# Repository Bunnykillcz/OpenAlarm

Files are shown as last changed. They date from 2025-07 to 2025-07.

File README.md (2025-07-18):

<p align="center">
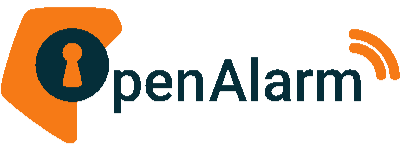
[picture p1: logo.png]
OpenAlarm Logo
  
</p>

<h1 align="center">OpenAlarm – Arduino Nano Opensource Alarm System</h1>

---
<p align="center">
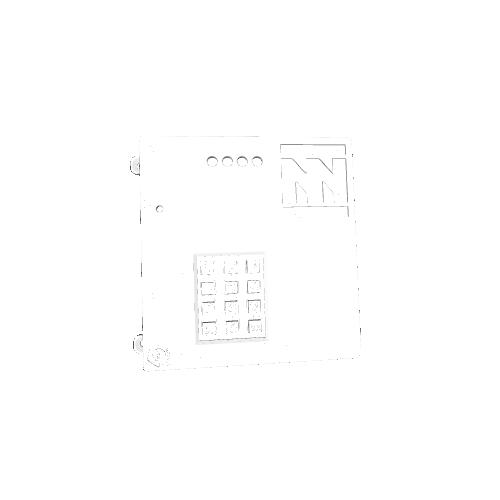
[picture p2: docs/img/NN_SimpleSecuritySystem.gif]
OpenAlarm Preview
  
</p>

## 📦 Overview

**OpenAlarm** is a fully open-source Arduino Nano–based hardware project, designed for hobbyists, students, and makers. The repository contains everything needed to build it, understand how it works, and adapt it to your own needs — **for personal and non-commercial use only**.

Included in this repo:

- ✅ Arduino Nano source code  
- 🔌 Electrical schematics and wiring diagrams  
- 📐 Mechanical dimensions (STL, DXF, etc.)  
- 📄 Full documentation and bill of materials  

---

## 🛠 What's Inside

- `/code` – Arduino sketches and libraries  
- `/schematics` – Circuit diagrams (PDF, Fritzing, etc.)  
- `/dimensions` – Mechanical files (STL, DXF, etc.)  
- `/docs` – Assembly guide, setup instructions, BOM  

---

## 🔧 Requirements

- Arduino Nano board  
- Components as listed in [`/docs/BOM.md`](/docs/BOM.md)
- Basic tools: soldering iron, USB cable, multimeter, etc.

---

## ⚖️ License

**Creative Commons Attribution-NonCommercial 4.0 International (CC BY-NC 4.0)**

> You are free to use, modify, and share this project **for personal or educational use only**. Commercial use is **not allowed**.

[Read the full license →](https://creativecommons.org/licenses/by-nc/4.0/)

For any inquiries, contact me at **info@nejedniko.cz**.

---

## 🤝 Contributions

Pull requests are welcome! If you have improvements, ideas, or bugfixes, feel free to fork and submit a PR.

---

## 📬 Contact

Submit issues in the [Issues](../../issues) tab.  
For anything else, contact me directly at **info@nejedniko.cz**.

---

## 💸 Support

Like the project?  
Want to keep the caffeine flowing so I can keep building stuff that beeps and blinks?

☕ **Invest in my caffeine addiction here:**  
[https://ko-fi.com/bunnykill](https://ko-fi.com/bunnykill)

---

> Made with precision, shared with purpose — powered by Arduino Nano.

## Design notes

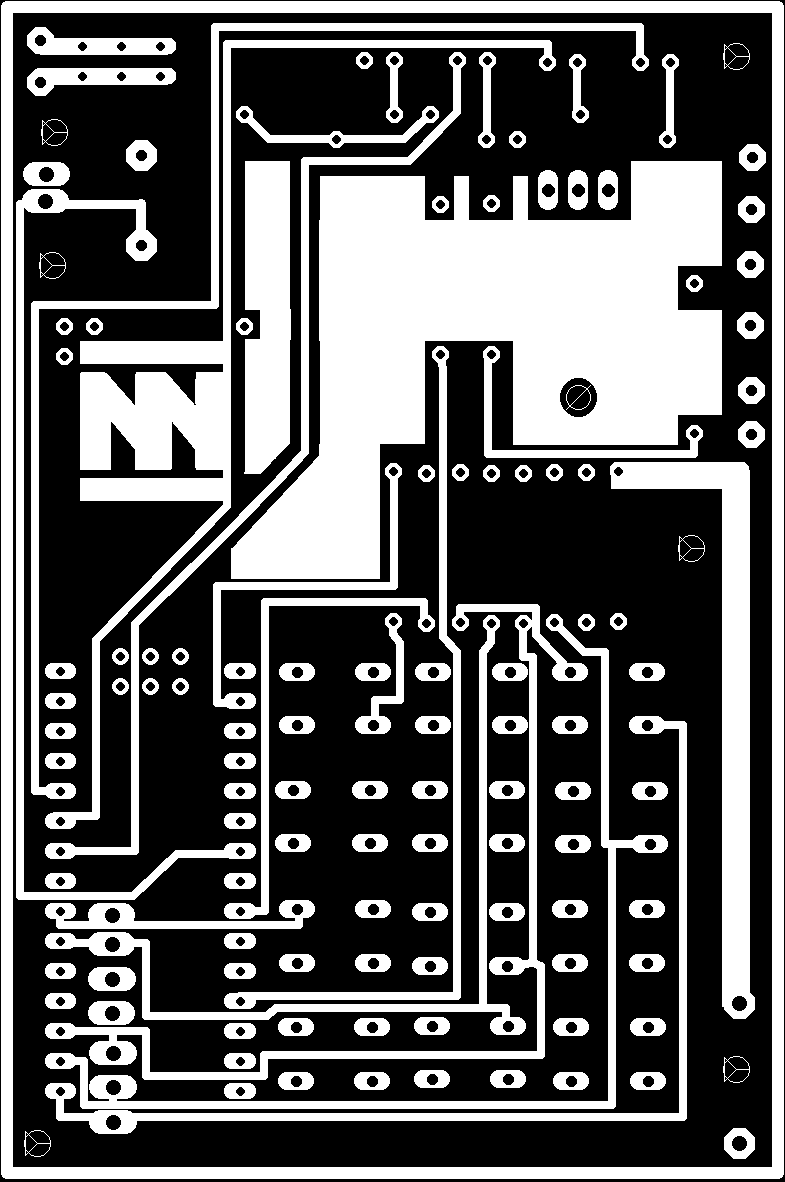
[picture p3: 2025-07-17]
schematics/NNOpenAlarm_rev01_Board_Top.png

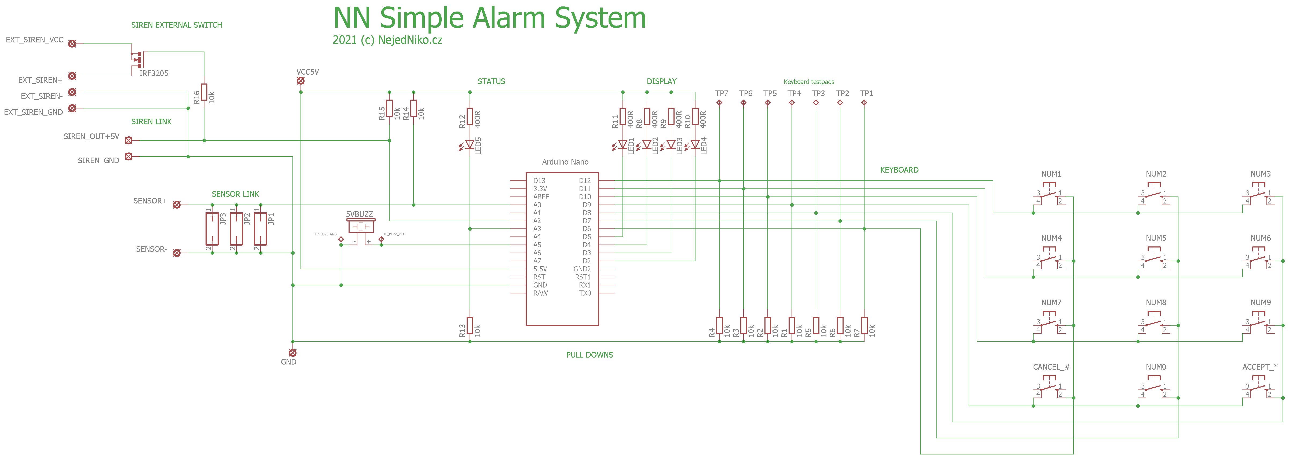
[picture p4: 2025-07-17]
schematics/NNOpenAlarm_rev01_Schematic.png

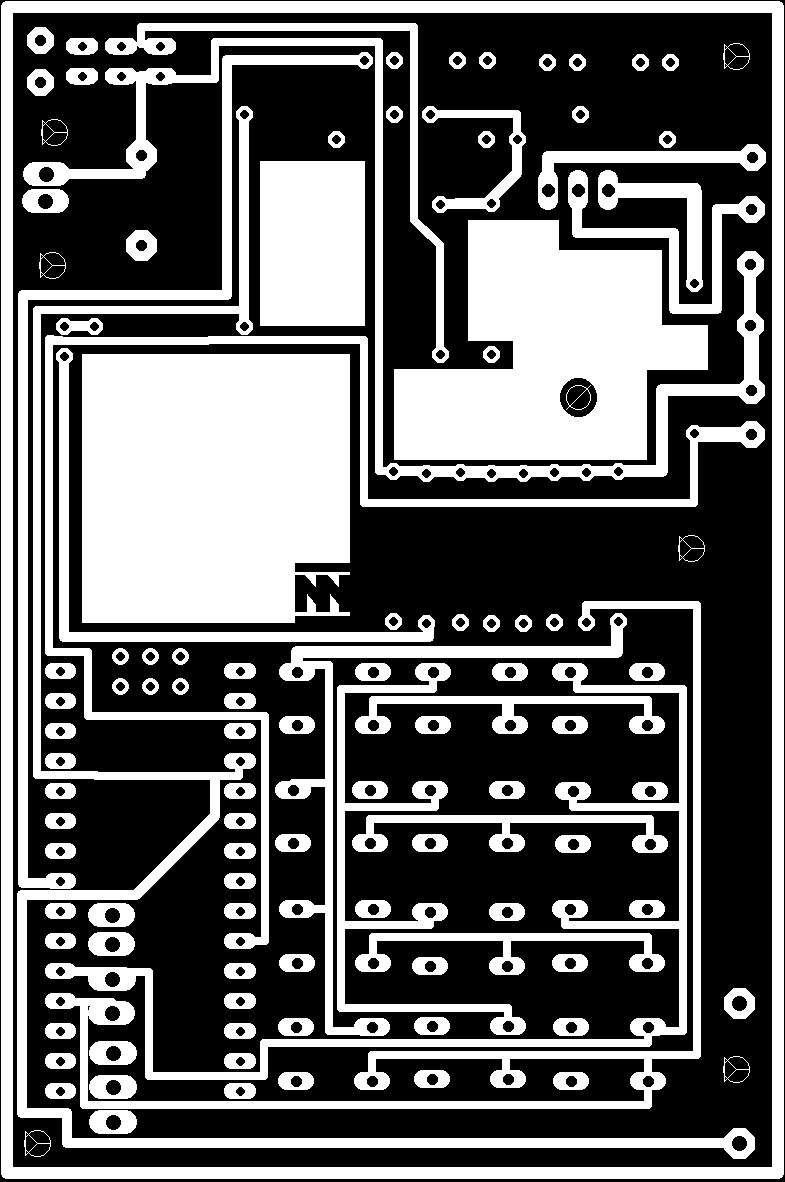
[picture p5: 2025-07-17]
schematics/NNOpenAlarm_rev01_Board_Bottom.png

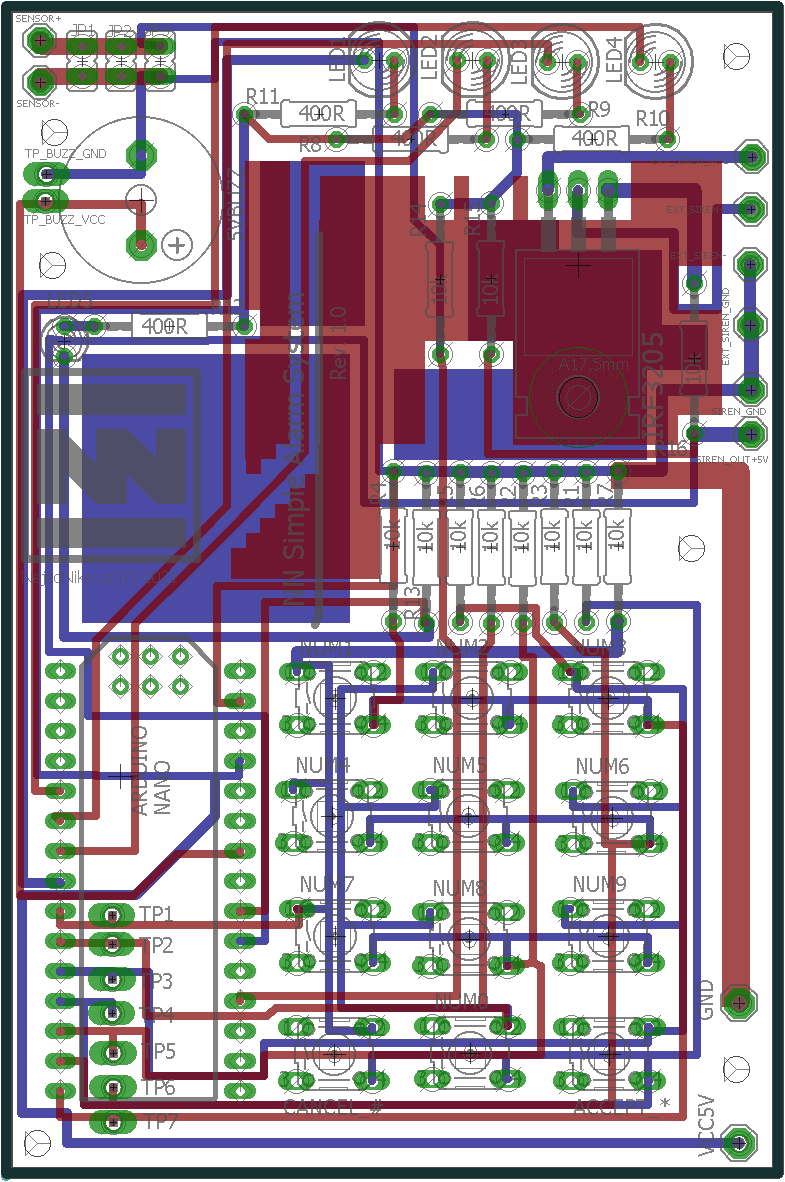
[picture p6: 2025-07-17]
schematics/NNOpenAlarm_rev01_BoardFull.png

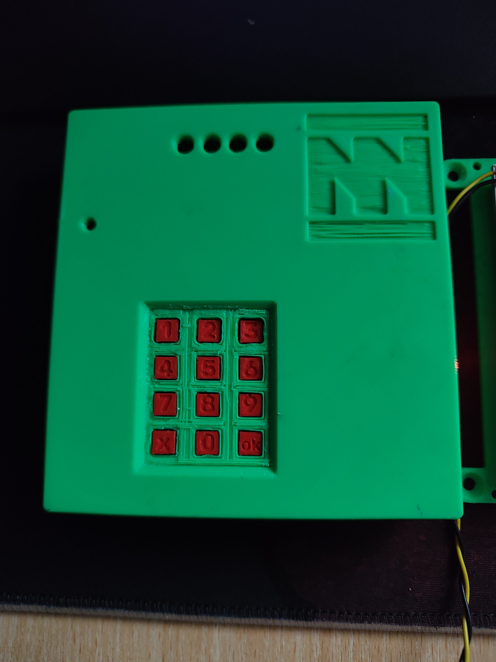
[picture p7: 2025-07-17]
docs/img/OA-top.jpg

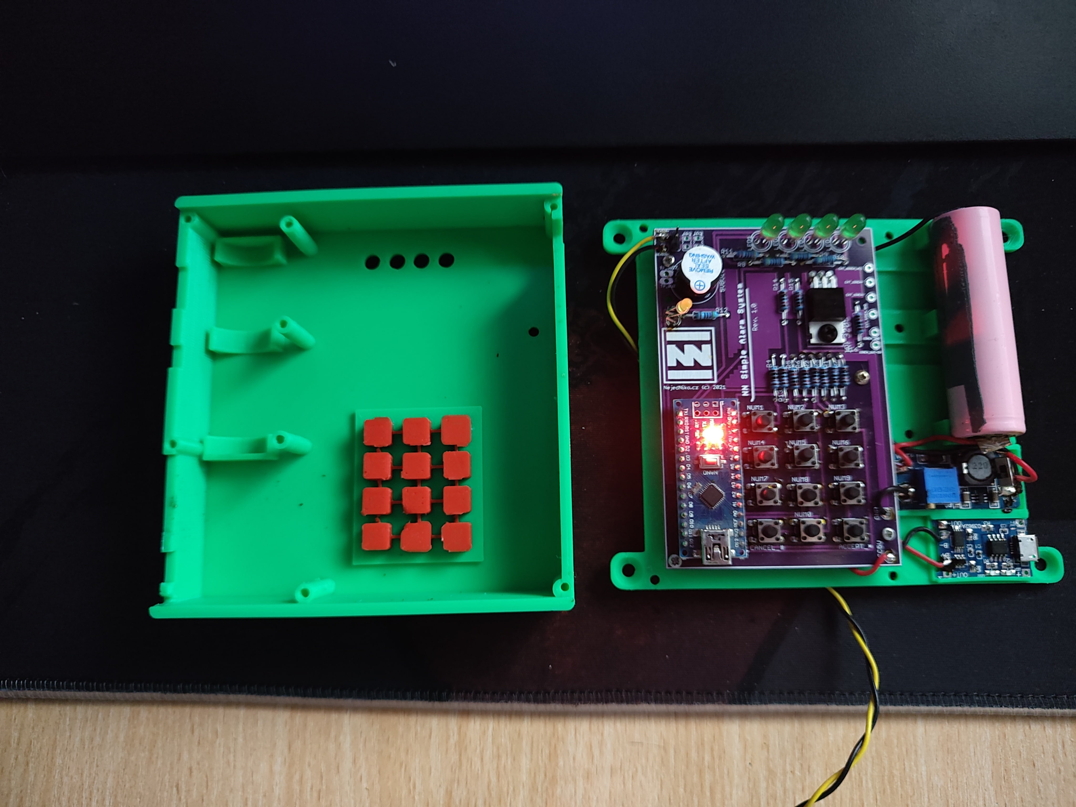
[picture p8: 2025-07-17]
docs/img/OA-insides.jpg

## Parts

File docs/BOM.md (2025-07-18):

# 🧾 Bill of Materials (BOM) – OpenAlarm

This document lists all the components, modules, and tools required to build the **OpenAlarm** system.

---

## 📦 Main Modules & Boards

| Component | Notes |
|---|---|
| 🔋 **Li-ion Battery (3.7–4.2 V)** | Power source |
| ⚡ **Step-Up Converter (0–3 V → 5 V+)** | Boosts battery voltage to usable levels |
| 🔌 **Charging Circuit** | Must include **overcharge** and **quick discharge protection IC** |
| 🧩 **3D Printed Case & Keyboard** | STL files available in `/dimensions/stl` |
| 🖧 **NN OpenAlarm Motherboard** | See detailed part list below |

---

## 🧠 NN OpenAlarm Motherboard Components

| Qty | Component | Notes |
|-----|---|---|
| 1x | **Buzzer** | Diameter: 10–15 mm |
| 11x | **Resistor** – 10 kΩ | Pull-down/pull-up logic |
| 5x | **Resistor** – 400 Ω | LED current limiters; optionally lower for higher brightness |
| 1x | **LED (3 mm)** | `LED5`, status indicator |
| 4x | **LED (5 mm)** | `LED1–LED4`, used for display |
| 12x | **Button Switch** | 6×6 mm tactile push buttons |
| 1x | **MOSFET IRF3205** | Optional – used to switch external 12 V siren (requires separate power) |
| 1x | **Arduino Nano** | Or compatible clone with USB and same pinout |
| 🧵 | **Wires** | For connecting all the components |

---

## 📐 Motherboard PCB Dimensions

- Width: **65 mm**  
- Height: **98 mm**

The board fits into the 3D printed case provided in `/dimensions/stl`. You are welcome to make your own as well.

---

## 🛠 Assembly Requirements

| Tool / Material | Notes |
|---|---|
| 🔩 Small Screws | For mounting case and components |
| 🔧 Screwdriver | |
| 🩹 Sticky Tape / Hot Glue | To secure internal components |
| 🖨 3D Printer | Or find someone to print the case for you |
| 💻 Computer | For uploading firmware from `/code/NNOpenAlarm/` |
| 🔥 Soldering Iron | Required for wiring and headers |
| 🧾 Motherboard PCB | Can be ordered from JLCPCB (see `/schematics/*.zip`) or made at home using monochrome 2-layer printouts |

---

## 🔌 Optional

| Item | Purpose |
|---|---|
| 🔌 **5 V Charger** | Optional, for permanent power supply (battery acts as backup) |
| ☕ **A Good Spirit** | Required for optimal results 😎 |

---

## 📝 Notes

- If you're using standard LEDs that require ~20mA, calculate exact resistor values using Ohm’s Law:  
  `R = (V_supply - V_LED) / I_LED`  
  Example for 5V supply, red LED (2V), 20 mA:  
  `R = (5 - 2) / 0.02 = 150 Ω`  
  Choose the closest higher standard value.

- 💡 **Note** that this project uses **highly sensitive LEDs** —  
- specifically **5 mm yellow** and **3 mm red** sensitive types that are bright enough at **5–10 mA**.  

---

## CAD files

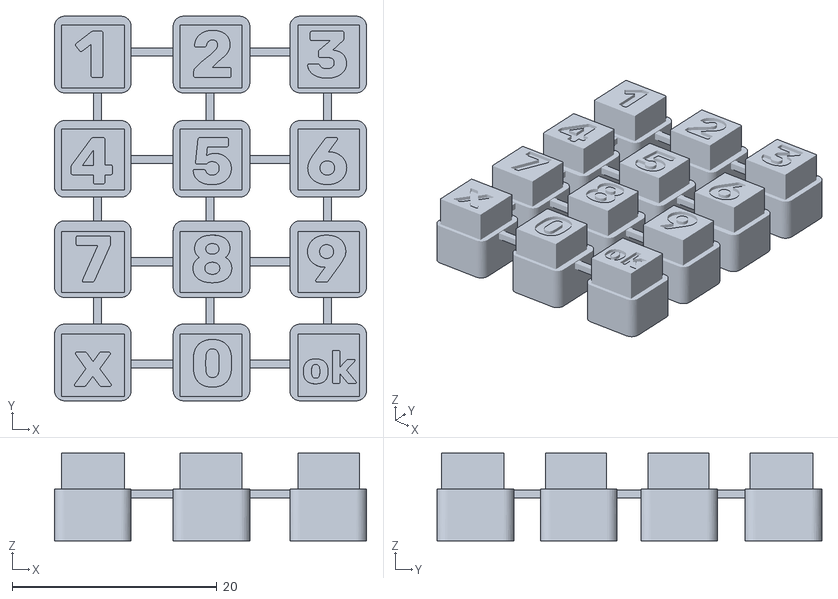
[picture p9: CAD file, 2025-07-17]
dimensions/stl/NN OpenAlarm - Keyboard_shorter.stl
30.5 x 37.6 x 8.60

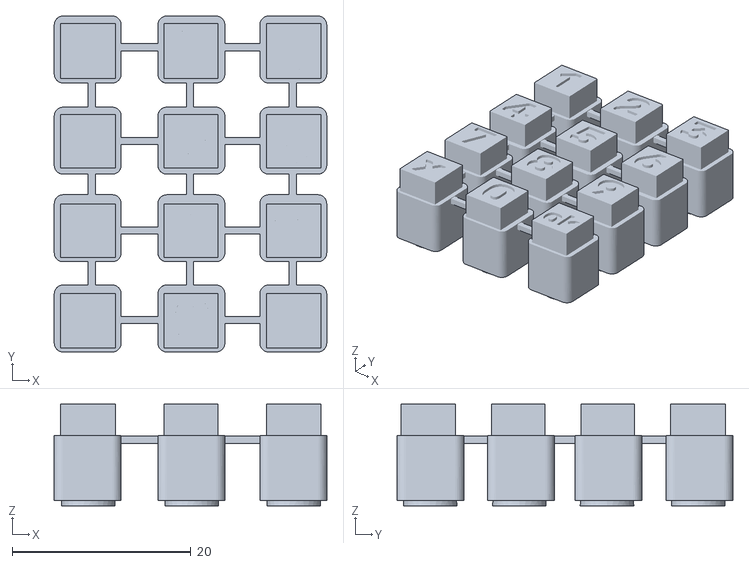
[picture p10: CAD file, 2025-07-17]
dimensions/stl/NN OpenAlarm - Keyboard.stl
30.5 x 37.6 x 11.4

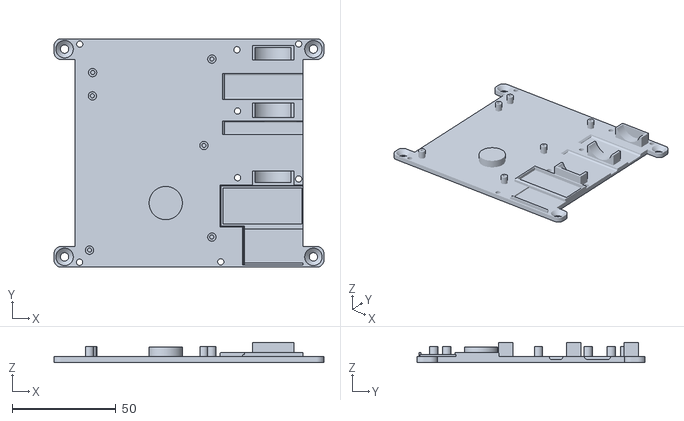
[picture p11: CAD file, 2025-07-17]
dimensions/stl/NN OpenAlarm - Base.stl
130.0 x 110.0 x 9.80

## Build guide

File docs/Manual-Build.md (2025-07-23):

# 🛠️ OpenAlarm Build Manual
## last-updated: 23.07.2025

Made by **NejedNiko.cz**  
(c) 2021–2025 — All rights reserved  
Licensed for non-commercial personal use

This manual guides you through building the OpenAlarm hardware step by step — from preparing the parts to uploading the software and testing everything. For best results, read the entire guide once before starting.

---

## A — The Hardware

### 1. Prepare everything you need

- Soldering iron + solder
- Printed case (3D print or CNC cut, see `/dimensions`)
- Ordered or self-etched PCB (I recommend [JLCPCB](https://jlcpcb.com))
- All parts listed in [docs/BOM.md](./BOM.md)
- Arduino Nano, step-up converter, Li-ion battery, charger module, LEDs, buzzer, resistors, etc.

> Tip: Check [docs/BOM.md](./BOM.md) for links and part numbers.

---

### 2. Soldering components

- Start with **small components first**, then larger ones (standard practice).
- Leave **Arduino Nano** for last.
- The board should be labeled with component positions. If not:
  - Refer to schematic diagrams and board photos
  - Check [docs/img/OA-mounting_detail.jpg](./img/OA-mounting_detail.jpg)

#### Tips:
- **LEDs**: Do not solder flush. Leave long legs. Only shorten them if the case doesn’t close cleanly.
- **LED leveling**: Use a piece of cardboard to keep them level and consistent.

---

### 2.a. Prepare the step-up module

- **Before soldering**: Set the step-up module to output **5V**.
- Power it with a Li-ion battery or a power supply.
- Measure the output voltage with a multimeter.
- Adjust the small screw until output is 5V (±0.05V).
- Once set, the module is ready to be used.

---

### 3. Wire modules

- After soldering, connect all modules with wires as per the connection diagram.
- Double-check with a **multimeter**:
  - Continuity between connections
  - Correct voltages before plugging in the battery

> Optional: If available, use a lab power supply to power the board and test functionality before inserting the battery.

🖼️ **Visual wiring reference**:  
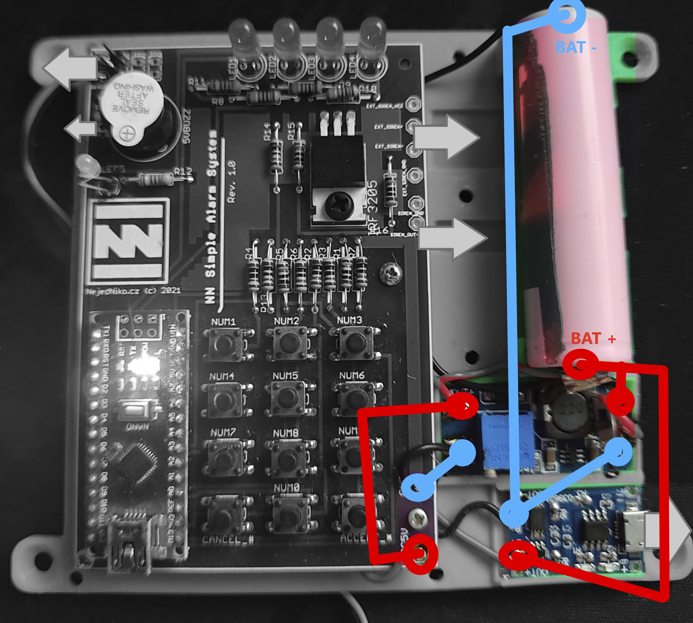
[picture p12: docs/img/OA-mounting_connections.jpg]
Connection guide


---

### 4. Connect the Li-ion battery

**⚠️ CAUTION: Li-ion batteries are dangerous if mishandled.**

- Use **spot welding** and **nickel strips**.
- **Never solder directly** onto the battery. This is a safety risk.
- If you choose to do so, you do it **at your own risk**.

> Personal note: I once soldered directly to a Li-ion cell. It didn’t explode, but it could have.

---

### 4.a. Sensor pins

- Solder wires or pin headers to the sensor input section (top left of the board).
- This helps later when attaching motion sensors or switches.

---

### 5. First power-on test

- Connect USB power or a charger to the charging module.
- Battery should start charging.
- Step-up module should power the main board.
- Arduino Nano should blink (default sketch is pre-uploaded).
- **Nothing should heat up.**

---

### 5.a. Fix into case

- Secure the modules using:
  - Double-sided tape or glue
  - Screws through mounting holes

---

### ✅ 6. Hardware finished!

If all steps went well, your OpenAlarm hardware is now built and ready for firmware upload.

---

## B — The Software

### 1. Prepare your system

- Use a PC/laptop that supports Arduino IDE
- Download IDE from [arduino.cc/en/software](https://www.arduino.cc/en/software)

---

### 2. Install & setup

- Install required **drivers** and **board support** for Arduino Nano
- If the Nano isn't detected, install missing packages via the Boards Manager

---

### 3. Open and configure the code

- Open the project:  
  [`code/NNOpenAlarm/NNOpenAlarm.ino`](../code/NNOpenAlarm/NNOpenAlarm.ino)

#### 3.a. Edit configuration

At the top of the code in a section properly commented:

```cpp
//Your PASSWORD HERE: (example: 9856)
const int n1 = 9; //first  digit
const int n2 = 8; //second digit
const int n3 = 5; //third  digit
const int n4 = 6; //fourth digit

int delay_time_ms_enter = 8000; //the delay for a person to enter the room and enter the code safely
int delay_time_ms_leave = 8000; //the delay for a person to leave before the alarm starts
bool beep_during_entry_sequence = true; //if the buzzer should beep while counting down the entry
```

Save your changes.

---

### 3.b. Upload a test sketch (optional but recommended)

- Upload the standard **Blink** example.
- If the LED blinks — your setup is working.

---

### 3.c. Upload OpenAlarm firmware

- Upload the modified `NNOpenAlarm.ino` sketch.
- Check the serial monitor for status output if needed.

---

### ✅ 4. Firmware ready!

- Disconnect and reconnect power.
- Press **OK** to arm the alarm (tip: unplug the siren while testing).
- It should beep.
- Press **Cancel** to disarm.

---

### 5. Final assembly

- Secure all parts inside with double-sided tape (or glue) and screws.
- Close the enclosure.
- Make sure nothing rattles.

---

### 6. Ready to use

Your hardware and software are now fully assembled and working.  
Continue to [Usage Manual](./Manual-Usage.md) to learn how to operate OpenAlarm.

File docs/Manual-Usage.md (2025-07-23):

* This content has not been written yet *

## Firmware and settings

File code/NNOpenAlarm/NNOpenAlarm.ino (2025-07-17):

/*
 _____  ___  _____  ___        ________ __    ___      ___   _______  ___      _______           __     ___           __       _______  ___      ___       ________ ___  ___ ________ ___________ _______ ___      ___ 
(\"   \|"  \(\"   \|"  \      /"       |" \  |"  \    /"  | |   __ "\|"  |    /"     "|         /""\   |"  |         /""\     /"      \|"  \    /"  |     /"       |"  \/"  /"       ("     _   "/"     "|"  \    /"  |
|.\\   \    |.\\   \    |    (:   \___/||  |  \   \  //   | (. |__) :||  |   (: ______)        /    \  ||  |        /    \   |:        |\   \  //   |    (:   \___/ \   \  (:   \___/ )__/  \\__(: ______)\   \  //   |
|: \.   \\  |: \.   \\  |     \___  \  |:  |  /\\  \/.    | |:  ____/|:  |    \/    |         /' /\  \ |:  |       /' /\  \  |_____/   )/\\  \/.    |     \___  \    \\  \/ \___  \      \\_ /   \/    |  /\\  \/.    |
|.  \    \. |.  \    \. |      __/  \\ |.  | |: \.        | (|  /     \  |___ // ___)_       //  __'  \ \  |___   //  __'  \  //      /|: \.        |      __/  \\   /   /   __/  \\     |.  |   // ___)_|: \.        |
|    \    \ |    \    \ |     /" \   :)/\  |\|.  \    /:  |/|__/ \   ( \_|:  (:      "|     /   /  \\  ( \_|:  \ /   /  \\  \|:  __   \|.  \    /:  |     /" \   :) /   /   /" \   :)    \:  |  (:      "|.  \    /:  |
 \___|\____\)\___|\____\)    (_______/(__\_|_|___|\__/|___(_______)   \_______\_______)    (___/    \___\_______(___/    \___|__|  \___|___|\__/|___|    (_______/ |___/   (_______/      \__|   \_______|___|\__/|___|
                                                                                                                                                                                                                       
Made by Nikola Nejedlý
2021-2022 (c) NejedNiko.cz
With the use of Arduino IDE, made for Arduino NANO

   _____      _   _   _                 
  / ____|    | | | | (_)                
 | (___   ___| |_| |_ _ _ __   __ _ ___ 
  \___ \ / _ \ __| __| | '_ \ / _` / __|
  ____) |  __/ |_| |_| | | | | (_| \__ \
 |_____/ \___|\__|\__|_|_| |_|\__, |___/
                               __/ |    
                              |___/     
//--------------------------------------------------------------------------------------------------------------------------------------------------------------------------------------------------------*/
//Your PASSWORD HERE: (example: 9856)
const int n1 = 9; //first  digit
const int n2 = 8; //second digit
const int n3 = 5; //third  digit
const int n4 = 6; //fourth digit

int delay_time_ms_enter = 8000; //the delay for a person to enter the room and enter the code safely
int delay_time_ms_leave = 8000; //the delay for a person to leave before the alarm starts
bool beep_during_entry_sequence = true; //if the buzzer should beep while counting down the entry

/*--------------------------------------------------------------------------------------------------------------------------------------------------------------------------------------------------------
  _____                                     
 |  __ \                                    
 | |__) | __ ___   __ _ _ __ __ _ _ __ ___  
 |  ___/ '__/ _ \ / _` | '__/ _` | '_ ` _ \ 
 | |   | | | (_) | (_| | | | (_| | | | | | |
 |_|   |_|  \___/ \__, |_|  \__,_|_| |_| |_|
                   __/ |                    
                  |___/                     
//--------------------------------------------------------------------------------------------------------------------------------------------------------------------------------------------------------*/

//BUZZER
const int pinBuzz = 19;

//D6-D12 = keyboard
const int pinK1 = 12;
const int pinK2 = 11;
const int pinK3 = 10;
const int pinK4 = 9;
const int pinKA = 6;
const int pinKB = 7;
const int pinKC = 8;

//D2-D5 = display (leds) -> 0 = active
const int pinD1 = 5;
const int pinD2 = 4;
const int pinD3 = 3;
const int pinD4 = 2;

//A3 =  status
const int pinS0 = 17;

//A2 = SIREN OUTPUT
const int pinSiren = 16;

//A0 = SENSORS INPUT
const int pinSensors = 14;

//code digit control
int digitsEntered = 0;
bool d1correct = false;
bool d2correct = false;
bool d3correct = false;
bool d4correct = false;

bool buttonPressed = false;
bool isOff = true;

int row = 0;
int rowcheck = 0;

bool AlertPending = false;
bool AlertActive = false;
bool AlarmPending = false;
bool AlarmActive = false;

unsigned long runtime = 0;
unsigned long ALERT_TIME_S = millis();

void setup() {
  pinMode(pinKA,      INPUT);
  pinMode(pinKB,      INPUT);
  pinMode(pinKC,      INPUT);
  pinMode(pinK1,      OUTPUT);
  pinMode(pinK2,      OUTPUT);
  pinMode(pinK3,      OUTPUT);
  pinMode(pinK4,      OUTPUT);

  digitalWrite(pinK1, LOW);
  digitalWrite(pinK2, LOW);
  digitalWrite(pinK3, LOW);
  digitalWrite(pinK4, LOW);
 
  pinMode(pinD1,     OUTPUT);
  pinMode(pinD2,     OUTPUT);
  pinMode(pinD3,     OUTPUT);
  pinMode(pinD4,     OUTPUT);
  
  digitalWrite(pinD1, HIGH);
  digitalWrite(pinD2, HIGH);
  digitalWrite(pinD3, HIGH);
  digitalWrite(pinD4, HIGH);
  
  pinMode(pinBuzz,    OUTPUT);
  pinMode(pinS0,      OUTPUT);
  pinMode(pinSiren,   OUTPUT);
  pinMode(pinSensors, INPUT);
  
  digitalWrite(pinS0,    LOW);
  digitalWrite(pinBuzz,  LOW);
  digitalWrite(pinSiren, LOW);
  
  Serial.begin(9600);
}

void loop() {

if(AlarmActive)
{
  //Serial.print("Sensor: ");
  //Serial.println(digitalRead(pinSensors)); //pin active on release
  if(digitalRead(pinSensors) == HIGH)
  {
    if(AlertPending == false)
    {
      if(beep_during_entry_sequence)
        Beep(150);
      
      ALERT_TIME_S = millis();
    }
    AlertPending = true;
  }

  if(beep_during_entry_sequence)
    if(AlertPending == true && AlertActive == false)
    {
      if(runtime % 3000 >= 2950) 
        Beep(50);
    }
  
  digitalWrite(pinK1, LOW);
  digitalWrite(pinK2, LOW);
  digitalWrite(pinK3, LOW);
  digitalWrite(pinK4, LOW);
  
  if(buttonPressed == false)
  {
    switch(row)
    {
      case 0:
      digitalWrite(pinK1, HIGH);
        if(digitalRead(pinKA) == HIGH)//1
          {
            buttonPressed = true;
            pressedNewDigit(1, digitsEntered++);
          }
        else
        if(digitalRead(pinKB) == HIGH)//2
          {
            buttonPressed = true;
            pressedNewDigit(2, digitsEntered++);
          }
        else
        if(digitalRead(pinKC) == HIGH)//3
          {
            buttonPressed = true;
            pressedNewDigit(3, digitsEntered++);
          }
        break;
      case 1:
      digitalWrite(pinK2, HIGH);
        if(digitalRead(pinKA) == HIGH)//4
          {
            buttonPressed = true;
            pressedNewDigit(4, digitsEntered++);
          }
        else
        if(digitalRead(pinKB) == HIGH)//5
          {
            buttonPressed = true;
            pressedNewDigit(5, digitsEntered++);
          }
        else
        if(digitalRead(pinKC) == HIGH)//6
          {
            buttonPressed = true;
            pressedNewDigit(6, digitsEntered++);
          }
        break;
      case 2:
      digitalWrite(pinK3, HIGH);
        if(digitalRead(pinKA) == HIGH)//7
          {
            buttonPressed = true;
            pressedNewDigit(7, digitsEntered++);
          }
        else
        if(digitalRead(pinKB) == HIGH)//8
          {
            buttonPressed = true;
            pressedNewDigit(8, digitsEntered++);
          }
        else
        if(digitalRead(pinKC) == HIGH)//9
          {
            buttonPressed = true;
            pressedNewDigit(9, digitsEntered++);
          }
        break;
      case 3:
      digitalWrite(pinK4, HIGH);
        if(digitalRead(pinKA) == HIGH)//#
          {
            buttonPressed = true;
            Serial.println("# (Cancel/Reset)");
            digitsEntered = 0;
            Beep(30);
            delay(30);
            Beep(30);
            delay(30);
            Beep(30);
            delay(30);
            Beep(30);
            delay(300);
          }
        else
        if(digitalRead(pinKB) == HIGH)//0
          {
            buttonPressed = true;
            pressedNewDigit(0, digitsEntered++);
          }
        else
        if(digitalRead(pinKC) == HIGH)//*
          {
            buttonPressed = true;
            Serial.println("* (OK/Enter)");
            
            if(digitsEntered >= 4)
              if(checkPassword() == true)
              {
                AlarmActive = false;
                Serial.println("<< ALARM DEACTIVATED >>");
                digitsEntered = 0;
                Beep(50);
                delay(50);
                Beep(50);
                delay(300);
                if(AlertActive || AlertPending)
                {
                  Serial.println("<< INTRUDER ALERT DEACTIVATED >>");
                  digitalWrite(pinSiren, LOW);
                  AlertActive  = false;
                  AlertPending = false;
                }
              }
              else
              {
                Beep(150);
                digitsEntered = 0;
              }
          }
        break;
    }
    rowcheck = 0;
  }
  else
  {
    switch(rowcheck)
    {
      case 0:
      digitalWrite(pinK1, HIGH);
        if(digitalRead(pinKA) == HIGH || digitalRead(pinKB) == HIGH || digitalRead(pinKC) == HIGH)//1,2,3
          {
            isOff = false;
          }
        break;
      case 1:
      digitalWrite(pinK2, HIGH);
        if(digitalRead(pinKA) == HIGH || digitalRead(pinKB) == HIGH || digitalRead(pinKC) == HIGH)//4,5,6
          {
            isOff = false;
          }
        break;
      case 2:
      digitalWrite(pinK3, HIGH);
        if(digitalRead(pinKA) == HIGH || digitalRead(pinKB) == HIGH || digitalRead(pinKC) == HIGH)//7,8,9
          {
            isOff = false;
          }
        break;
      case 3:
      digitalWrite(pinK4, HIGH);
        if(digitalRead(pinKA) == HIGH || digitalRead(pinKB) == HIGH || digitalRead(pinKC) == HIGH)//#,0,*
          {
            isOff = false;
          }
        break;
    }
    rowcheck++;
    if(rowcheck >= 4 && isOff == true)
      buttonPressed = false;
    else
    if(rowcheck >= 4)
    {
      rowcheck = 0;
      isOff = true;
    }
  }
  
  lightUp(digitsEntered);
  
  row++;
  if(row >= 4)
    row = 0;

    //blinking-active = yes
  if(runtime % 3000 >= 2000 || AlarmPending == true || AlertPending == true) 
    digitalWrite(pinS0, LOW);
  else
    digitalWrite(pinS0, HIGH);

  }
  else
  {
    digitalWrite(pinK4, HIGH);
      if(digitalRead(pinKC) == HIGH)//#,0,*
        {
          AlarmPending = true;
          Serial.println("<< ALARM SET >>");
          Beep(50);
          delay(50);
          Beep(50);
          delay(50);
          Beep(50);
          ALERT_TIME_S = millis();
        }
    //blinking-active = no
    digitalWrite(pinS0, HIGH); 
  }

  runtime = millis();
  
  //Leave the room - timer
  if(AlarmPending == true)
  {
    //Serial.print("TIME: ");
    //Serial.println(runtime - ALERT_TIME_S);
    Beep(70);
    if(runtime - ALERT_TIME_S >= delay_time_ms_leave)
    {
      for(int i = 10; i > 0; i--)
      { 
        delay(50);
        Beep(50);
      }
      AlarmPending = false;
      AlarmActive = true;
      Serial.println("<< ALARM ACTIVATED >>");
    }
    delay(430);
    //IF CANCELLED
    digitalWrite(pinK4, HIGH);
    if(digitalRead(pinKA) == HIGH) // Cancel button
      {
        delay(10);
        Beep(100);
        delay(50);
        Beep(100);
        AlarmPending = false;
        AlarmActive = false;
      }
  }
  //Enter the room - timer
  if(AlertPending == true)
  {
    //Serial.print("TIME: ");
    //Serial.println(runtime - ALERT_TIME_S);
    if(runtime - ALERT_TIME_S >= delay_time_ms_enter)
    {
      Beep(150);
      AlertPending = false;
      AlertActive = true;
      Serial.println("<< INTRUDER ALERT >>");
      digitalWrite(pinSiren, HIGH);
    }
  }
}

void pressedNewDigit(int digit, int id)
{
  if(id < 4)
  {
    if(id == 0)
      if(digit == n1)
      {
        d1correct = true;
        Serial.println("1.OK");
      }
      else
        d1correct = false;
    if(id == 1)
    if(digit == n2)
      {
        d2correct = true;
        Serial.println("2.OK");
      }
      else
        d2correct = false;
    
    if(id == 2)
    if(digit == n3)
      {
        d3correct = true;
        Serial.println("3.OK");
      }
      else
        d3correct = false;
      
    if(id == 3)
    if(digit == n4)
      {
        d4correct = true;
        Serial.println("4.OK");
      }
      else
        d4correct = false;
    
    Serial.println(digit);
    delay(100);
  }
  Beep(100);
}

void lightUp(int dEn)
{
  digitalWrite(pinD1, HIGH);
  digitalWrite(pinD2, HIGH);
  digitalWrite(pinD3, HIGH);
  digitalWrite(pinD4, HIGH);
  
  if(dEn >= 1)
    digitalWrite(pinD1, LOW);
  if(dEn >= 2)
    digitalWrite(pinD2, LOW);
  if(dEn >= 3)
    digitalWrite(pinD3, LOW);
  if(dEn >= 4)
    digitalWrite(pinD4, LOW);    
}

bool checkPassword()
{
  if(d1correct == true)
  if(d2correct == true)
  if(d3correct == true)
  if(d4correct == true)
  {
    Serial.println("Password OK");
    return true;
  }
  
  Serial.println("Password BAD");
  return false;
}

void Beep(int t)
{
    digitalWrite(pinBuzz, HIGH);
    delay(t);
    digitalWrite(pinBuzz, LOW);
}

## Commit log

2025-07-17 data, images, ...
    [NN OpenAlarm - Base.stl, NN OpenAlarm - Keyboard.stl, NN OpenAlarm - Keyboard_shorter.stl]
2026-11-03 Update licensing information and documentation
    - Replaced the existing license text with the NejedNiko Free Use License (NFUL) v1.1 and NFUL-3D v1.0 in LICENSE file.
    - Revised README.md to clarify project details and licensing.
    - Enhanced BOM.md with clearer component specifications and assembly instructions.
    - Streamlined Manual-Build.md for better readability and updated assembly steps.
    - Completed Manual-Usage.md with detailed keypad controls and alarm operation instructions.
    - Added NNlogo.png for branding in documentation.
